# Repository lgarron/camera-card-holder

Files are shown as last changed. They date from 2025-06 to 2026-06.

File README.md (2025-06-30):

# Stacked camera card holder 

Presenting a compact "print-in-place" card holder to stack your SD cards or CFExpress B cards!

Video: https://www.youtube.com/watch?v=bbGzAtc4VuA

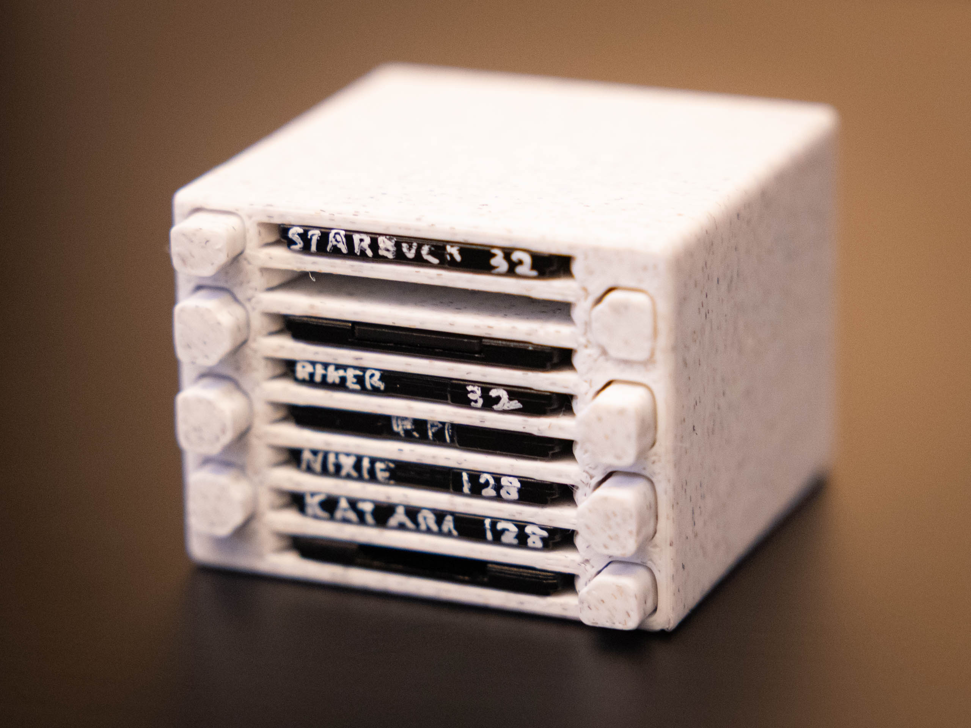
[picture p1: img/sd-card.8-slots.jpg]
Image of the 8-slot SD card variation


Find on MakerWorld at: https://makerworld.com/en/models/1563816-stacked-sd-card-cfexpress-type-b-card-holder

---------

I wanted something compact that I could attach to my desk, where all the cards can be individually accessed from the front with an "eject" button. I find the result to be very satisfying and practical.

Note that:

- The cards should stay in their slots during normal handling of the case, but this is *not* designed to take on-the-go. (But feel free to adapt the model to include a closing lid!)
- Versions are supported with 4/6/8/10 slots for both card types, and each build plate comes with a tool to snap the supports inside the model. (You only need this tool once per type of card, even if you print multiple designs with different numbers of slots.) Look at [1:25 in the video](https://www.youtube.com/watch?v=bbGzAtc4VuA&t=85s), or perform the following steps for each slot:
  - Hold the snapping tool with your index finger through the loop.
  - Insert into the slot so the longer side is up against the side that has the "eject" button for that slot.
  - Press down, keep the bottom of the tool on the eject button side, and move the top of the tool away.
  - If you really want to avoid using the the tool, you can place a card into a slot and then give it a strong and quick push. This should successfully snap the internal supports for materials in most prints, although I would still recommend using the snapping tool instead.
- The design is easily tuned for other card sizes (or even more slots), but I've only tested for SD cards and CFExpress Type B so far.
- I've found that the design looks and functions nicest using the following filaments
  - [PLA Marble — white](https://us.store.bambulab.com/products/pla-marble?id=41003162992776)
  - [PLA-CF — any color](https://us.store.bambulab.com/products/pla-cf)

The design is implemented entirely in OpenSCAD (https://openscad.org/) is open-sourced under the Creative Commands Attribution-ShareAlike 4.0 International license at: https://github.com/lgarron/camera-card-holder

## Building

This code uses:

- the snapshot channel of OpenSCAD, and
- the [`scad`](https://www.npmjs.com/package/scad) package on `npm`.

Here's an example of how to work on the code on macOS. I personally use [Homebrew](https://brew.sh/) to install `bun` and OpenSCAD:

```shell
brew install bun openscad@snapshot

git clone https://github.com/lgarron/camera-card-holder && cd camera-card-holder
make setup

open -a OpenSCAD ./*.scad
```

To build all variants the way I do, install `openscad-auto`:

```shell
brew install lgarron/lgarron/openscad-auto
make build-for-publish
make build
```

## Compatibility

Note that the code uses and unmerged and unreleased feature for OpenSCAD, naming its groups: https://github.com/openscad/openscad/pull/5942

Stable OpenSCAD is compatible with this, but may show warnings.

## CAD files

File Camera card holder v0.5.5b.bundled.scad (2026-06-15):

// Stacked camera card holder
// Lucas Garron
// v0.5.5 — manually bundled
// License: Creative Commons Attribution-NonCommercial-ShareAlike 4.0 International
//
// This file has been manually bundled and heavily modified to work around incompatibilities with Bambu's rendering vs. OpenSCAD.
// Therefore, it contains some extremely hacky and unmaintainable workarounds.
// For the original source, see: https://github.com/lgarron/camera-card-holder

CARD_TYPE = "SD Card"; // ["SD Card", "CFExpress B"]

NUMBER_OF_SLOTS = 4;

INCLUDE_CARD_TYPE_ENGRAVING = false;

/* [Debug] */

INCLUDE_DESIGN_VERSION_ENGRAVING = false;
DEBUG_EXCLUDE_CASING = false;

/* [Hidden] */

// This empty block prevents any following `CONSTANT_CASE` variables from being settable in the customizer.
// This prevents pathological interactions with persisted customizer values that are meant to be controlled exclusively by `VARIANT`.
{};

VARIANT = "default";

VERSION_TEXT = "v0.5.5b";

VARIANT_DATA = [
  [
    "default",
    [
      [
        ["DUAL_COLOR", false],
        ["DEEP_SECONDARY_COLOR", false],
        ["VARIANT_NUMBER_OF_SLOTS", NUMBER_OF_SLOTS],
        ["CF_EXPRESS_B", CARD_TYPE == "CFExpress B"],
        ["VARIANT_INCLUDE_DESIGN_VERSION_ENGRAVING", INCLUDE_DESIGN_VERSION_ENGRAVING],
      ],
    ],
  ],
  [
    "dual-color",
    [
      [
        ["DUAL_COLOR", true],
      ],
    ],
  ],
  [
    "deep-secondary-color",
    [
      [
        ["DEEP_SECONDARY_COLOR", true],
      ],
    ],
  ],
  [
    "6-slots",
    [
      [
        ["VARIANT_NUMBER_OF_SLOTS", 6],
      ],
    ],
  ],
  [
    "8-slots",
    [
      [
        ["VARIANT_NUMBER_OF_SLOTS", 8],
      ],
    ],
  ],
  [
    "10-slots",
    [
      [
        ["VARIANT_NUMBER_OF_SLOTS", 10],
      ],
    ],
  ],
  [
    "CFExpress-B",
    [
      [
        ["CF_EXPRESS_B", true],
      ],
    ],
  ],
  [
    "unengraved",
    [
      [
        ["VARIANT_INCLUDE_DESIGN_VERSION_ENGRAVING", false],
      ],
    ],
  ],
];
/*

// Allows specifying multiple variants to be rendered by `openscad-auto`: https://github.com/lgarron/dotfiles/blob/main/scripts/app-tools/openscad-auto.rs
//
// Each variant is a string, which must defined as an entry in a global BOSL2 struct named `VARIANT_DATA`.
//
// - The struct must contain an entry with the key `"default"`.
// - Keys are used in file names.
//   - They must not contain the character `.`, as this is used to compose variants (see below).
//   - Keys are used to create file names, so it is worth using names that will be as clear as possible in this context.
// - The value of each entry is a list containing:
//   - A required first item with a BOSL2 struct specifying a mapping of parameter names to values.
//   - An optional second item containing a list of parent variants to inherit from.
//     - Later entries override earlier entries.
//
// Each variant falls back to the parameter value from the `"default"` entry if it is not specified among the ancestors of a given entry.
// Note that the top-level order of entries has no effect on the parameter calculations. Parameter inheritance for a variant depends solely on the ordering of its parents (and their parents, recursively).
//
// The variant is specified in a global `VARIANT` var.
//
// - Multiple variants may be composed by specifying them with a `.` inbetween.
//   - Note that such variants can be defined explicitly in `VARIANT_DATA` by specifying those variants as parents. However, the compositional approach is a very convenient mechanism to avoid boilerplate.
//
// Parameters are computed by calling `get_parameter(parameter_name)` after `VARIANT` and `VARIANT_DATA` have been defined.
//
// Example usage:

VARIANT = "default"; // ["default", "no-version", "mini", "mini.normal-height"]

// This empty block prevents any following `CONSTANT_CASE` variables from being settable in the customizer.
// This prevents pathological interactions with persisted customizer values that are meant to be controlled exclusively by `VARIANT`.
{};

VARIANT_DATA = [
  [
    "default",
    [
      [
        ["TOTAL_HEIGHT", 5],
        ["TRIANGLE_EDGE_LENGTH", 25],
        ["INCLUDE_DESIGN_VERSION_ENGRAVING", true],
      ],
    ],
  ],
  [
    "no-version",
    [
      [
        ["INCLUDE_DESIGN_VERSION_ENGRAVING", false],
      ],
    ],
  ],
  [
    "mini",
    [
      [
        ["TOTAL_HEIGHT", 3],
        ["TRIANGLE_EDGE_LENGTH", 15],
      ],
      // Don't include the version for `mini` (it's small)
      ["no-version"]
    ],
  ],
  [
    "normal-height",
    [
      [
        ["TOTAL_HEIGHT", 5],
      ],
    ],
  ]
];

include <./node_modules/scad/variants.scad>

TOTAL_HEIGHT = get_parameter("TOTAL_HEIGHT");
TRIANGLE_EDGE_LENGTH = get_parameter("TRIANGLE_EDGE_LENGTH");
INCLUDE_DESIGN_VERSION_ENGRAVING = get_parameter("INCLUDE_DESIGN_VERSION_ENGRAVING");

*/

include <BOSL2/std.scad>

/*

type undef = undefined;
type ParameterValue = string | number;

type Struct<KeyType, ValueType> = [string, ValueType][];
type VariantID = string;
type ParameterName = string;
type VariantParameters = Struct<ParameterName, ParameterValue>;
type VariantInheritanceChain = VariantID[]; // Semantics: inheritance chain (later entries take priority)
type VariantEntry =
  | [VariantParameters]
  | [VariantParameters, VariantInheritanceChain];
type VariantData = Struct<VariantID, VariantEntry>;

// Global vars which must be set by the calling code.
export const VARIANT: string; // Variants delimited by `.`
export const VARIANT_DATA: VariantData;

*/

// function __variants__variant_parameters(variant_entry: VariantEntry): VariantParameters;
function __variants__variant_parameters(variant_entry) = variant_entry[0];
// function __variants__variant_parents(variant_entry: VariantEntry): [VariantID];
function __variants__variant_parents(variant_entry) = len(variant_entry) > 1 ? variant_entry[1] : [];

// function __variants__maybe_get_parameter_for_variant(parameter_name: ParameterName, variant_id: VariantID, variant_ids_in_recursion_stack_for_cycle_detection: VariantID[]): ParameterValue | undef;
function __variants__maybe_get_parameter_for_variant(parameter_name, variant_id, variant_ids_in_recursion_stack_for_cycle_detection) =
  // echo("__variants__maybe_get_parameter_for_variant", parameter_name, variant_id, variant_ids_in_recursion_stack_for_cycle_detection)
  assert(is_undef(str_find(variant_id, ".")), "Encountered a variant which contains the period (`.`) character. This character is used to delimit variants, and cannot be part of a variant ID directly")
  assert(!in_list(variant_id, variant_ids_in_recursion_stack_for_cycle_detection), str("Encountered recursively defined variants at the following variant: ", variant_id))
  let (
    variant_entry = struct_val(VARIANT_DATA, variant_id),
  ) assert(!is_undef(variant_entry), str("Variant is missing: ", variant_id)) // Technically we're doing unnecessary string concatentation in the "happy" path, but this should be cheap enough.
  let (
    direct_value = struct_val(__variants__variant_parameters(variant_entry), parameter_name)
  ) is_undef(direct_value) ? __variants__maybe_get_parameter_for_variants(parameter_name, __variants__variant_parents(variant_entry), concat(variant_ids_in_recursion_stack_for_cycle_detection, [variant_id])) : direct_value;;

// function __variants__maybe_get_parameter_for_variants(parameter_name: ParameterName, variants: VariantID[], variant_ids_in_recursion_stack_for_cycle_detection: VariantID[]): ParameterValue | undef;
function __variants__maybe_get_parameter_for_variants(parameter_name, variant_ids, variant_ids_in_recursion_stack_for_cycle_detection) =
  // echo("__variants__maybe_get_parameter_for_variants", parameter_name, variant_ids, variant_ids_in_recursion_stack_for_cycle_detection)
  len(variant_ids) == 0 ? undef
  : (
    let (maybe_value = __variants__maybe_get_parameter_for_variant(parameter_name, last(variant_ids), variant_ids_in_recursion_stack_for_cycle_detection)) is_undef(maybe_value) ? __variants__maybe_get_parameter_for_variants(parameter_name, list_head(variant_ids), variant_ids_in_recursion_stack_for_cycle_detection) : maybe_value
  );
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

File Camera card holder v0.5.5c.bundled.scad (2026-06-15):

// Stacked camera card holder
// Lucas Garron
// v0.5.5c — manually bundled
// License: Creative Commons Attribution-NonCommercial-ShareAlike 4.0 International
//
// This file has been manually bundled and heavily modified to work around incompatibilities with Bambu's rendering vs. OpenSCAD.
// Therefore, it contains some extremely hacky and unmaintainable workarounds.
// For the original source, see: https://github.com/lgarron/camera-card-holder

CARD_TYPE = "SD Card"; // ["SD Card", "CFExpress B"]

NUMBER_OF_SLOTS = 4;

INCLUDE_CARD_TYPE_ENGRAVING = false;

/* [Design parameters] */

CASING_OUTER_THICKNESS_X = 3.5;
CASING_OUTER_THICKNESS_Z = 2;
CASING_BACK_THICKNESS_Y = 1;
CASING_DISTANCE_BETWEEN_CARDS_Z = 1.5;

/* [Debug] */

INCLUDE_DESIGN_VERSION_ENGRAVING = false;
STRUCTURAL_COLORING = false;
DEBUG_EXCLUDE_CASING = false;

/* [Hidden] */

// Incompatible with Bambu rendering.
DUAL_COLOR = false;
DEEP_SECONDARY_COLOR = false;

// This empty block prevents any following `CONSTANT_CASE` variables from being settable in the customizer.
// This prevents pathological interactions with persisted customizer values that are meant to be controlled exclusively by `VARIANT`.
{};

module structural_color(color) {
  color(STRUCTURAL_COLORING ? color : "silver") {
    children();
  }
}

VARIANT = "default";

VERSION_TEXT = "v0.5.5c";

VARIANT_DATA = [
  [
    "default",
    [
      [
        ["VARIANT_DUAL_COLOR", DUAL_COLOR],
        ["VARIANT_DEEP_SECONDARY_COLOR", DEEP_SECONDARY_COLOR],
        ["VARIANT_NUMBER_OF_SLOTS", NUMBER_OF_SLOTS],
        ["CF_EXPRESS_B", CARD_TYPE == "CFExpress B"],
        ["VARIANT_INCLUDE_DESIGN_VERSION_ENGRAVING", INCLUDE_DESIGN_VERSION_ENGRAVING],
      ],
    ],
  ],
  [
    "dual-color",
    [
      [
        ["VARIANT_DUAL_COLOR", true],
      ],
    ],
  ],
  [
    "deep-secondary-color",
    [
      [
        ["VARIANT_DEEP_SECONDARY_COLOR", true],
      ],
    ],
  ],
  [
    "6-slots",
    [
      [
        ["VARIANT_NUMBER_OF_SLOTS", 6],
      ],
    ],
  ],
  [
    "8-slots",
    [
      [
        ["VARIANT_NUMBER_OF_SLOTS", 8],
      ],
    ],
  ],
  [
    "10-slots",
    [
      [
        ["VARIANT_NUMBER_OF_SLOTS", 10],
      ],
    ],
  ],
  [
    "CFExpress-B",
    [
      [
        ["CF_EXPRESS_B", true],
      ],
    ],
  ],
  [
    "unengraved",
    [
      [
        ["VARIANT_INCLUDE_DESIGN_VERSION_ENGRAVING", false],
      ],
    ],
  ],
];
/*

// Allows specifying multiple variants to be rendered by `openscad-auto`: https://github.com/lgarron/dotfiles/blob/main/scripts/app-tools/openscad-auto.rs
//
// Each variant is a string, which must defined as an entry in a global BOSL2 struct named `VARIANT_DATA`.
//
// - The struct must contain an entry with the key `"default"`.
// - Keys are used in file names.
//   - They must not contain the character `.`, as this is used to compose variants (see below).
//   - Keys are used to create file names, so it is worth using names that will be as clear as possible in this context.
// - The value of each entry is a list containing:
//   - A required first item with a BOSL2 struct specifying a mapping of parameter names to values.
//   - An optional second item containing a list of parent variants to inherit from.
//     - Later entries override earlier entries.
//
// Each variant falls back to the parameter value from the `"default"` entry if it is not specified among the ancestors of a given entry.
// Note that the top-level order of entries has no effect on the parameter calculations. Parameter inheritance for a variant depends solely on the ordering of its parents (and their parents, recursively).
//
// The variant is specified in a global `VARIANT` var.
//
// - Multiple variants may be composed by specifying them with a `.` inbetween.
//   - Note that such variants can be defined explicitly in `VARIANT_DATA` by specifying those variants as parents. However, the compositional approach is a very convenient mechanism to avoid boilerplate.
//
// Parameters are computed by calling `get_parameter(parameter_name)` after `VARIANT` and `VARIANT_DATA` have been defined.
//
// Example usage:

VARIANT = "default"; // ["default", "no-version", "mini", "mini.normal-height"]

// This empty block prevents any following `CONSTANT_CASE` variables from being settable in the customizer.
// This prevents pathological interactions with persisted customizer values that are meant to be controlled exclusively by `VARIANT`.
{};

VARIANT_DATA = [
  [
    "default",
    [
      [
        ["TOTAL_HEIGHT", 5],
        ["TRIANGLE_EDGE_LENGTH", 25],
        ["INCLUDE_DESIGN_VERSION_ENGRAVING", true],
      ],
    ],
  ],
  [
    "no-version",
    [
      [
        ["INCLUDE_DESIGN_VERSION_ENGRAVING", false],
      ],
    ],
  ],
  [
    "mini",
    [
      [
        ["TOTAL_HEIGHT", 3],
        ["TRIANGLE_EDGE_LENGTH", 15],
      ],
      // Don't include the version for `mini` (it's small)
      ["no-version"]
    ],
  ],
  [
    "normal-height",
    [
      [
        ["TOTAL_HEIGHT", 5],
      ],
    ],
  ]
];

include <./node_modules/scad/variants.scad>

TOTAL_HEIGHT = get_parameter("TOTAL_HEIGHT");
TRIANGLE_EDGE_LENGTH = get_parameter("TRIANGLE_EDGE_LENGTH");
INCLUDE_DESIGN_VERSION_ENGRAVING = get_parameter("INCLUDE_DESIGN_VERSION_ENGRAVING");

*/

include <BOSL2/std.scad>

/*

type undef = undefined;
type ParameterValue = string | number;

type Struct<KeyType, ValueType> = [string, ValueType][];
type VariantID = string;
type ParameterName = string;
type VariantParameters = Struct<ParameterName, ParameterValue>;
type VariantInheritanceChain = VariantID[]; // Semantics: inheritance chain (later entries take priority)
type VariantEntry =
  | [VariantParameters]
  | [VariantParameters, VariantInheritanceChain];
type VariantData = Struct<VariantID, VariantEntry>;

// Global vars which must be set by the calling code.
export const VARIANT: string; // Variants delimited by `.`
export const VARIANT_DATA: VariantData;

*/

// function __variants__variant_parameters(variant_entry: VariantEntry): VariantParameters;
function __variants__variant_parameters(variant_entry) = variant_entry[0];
// function __variants__variant_parents(variant_entry: VariantEntry): [VariantID];
function __variants__variant_parents(variant_entry) = len(variant_entry) > 1 ? variant_entry[1] : [];

// function __variants__maybe_get_parameter_for_variant(parameter_name: ParameterName, variant_id: VariantID, variant_ids_in_recursion_stack_for_cycle_detection: VariantID[]): ParameterValue | undef;
function __variants__maybe_get_parameter_for_variant(parameter_name, variant_id, variant_ids_in_recursion_stack_for_cycle_detection) =
  // echo("__variants__maybe_get_parameter_for_variant", parameter_name, variant_id, variant_ids_in_recursion_stack_for_cycle_detection)
  assert(is_undef(str_find(variant_id, ".")), "Encountered a variant which contains the period (`.`) character. This character is used to delimit variants, and cannot be part of a variant ID directly")
  assert(!in_list(variant_id, variant_ids_in_recursion_stack_for_cycle_detection), str("Encountered recursively defined variants at the following variant: ", variant_id))
  let (
    variant_entry = struct_val(VARIANT_DATA, variant_id),
  ) assert(!is_undef(variant_entry), str("Variant is missing: ", variant_id)) // Technically we're doing unnecessary string concatentation in the "happy" path, but this should be cheap enough.
  let (
    direct_value = struct_val(__variants__variant_parameters(variant_entry), parameter_name)
  ) is_undef(direct_value) ? __variants__maybe_get_parameter_for_variants(parameter_name, __variants__variant_parents(variant_entry), concat(variant_ids_in_recursion_stack_for_cycle_detection, [variant_id])) : direct_value;;

// function __variants__maybe_get_parameter_for_variants(parameter_name: ParameterName, variants: VariantID[], variant_ids_in_recursion_stack_for_cycle_detection: VariantID[]): ParameterValue | undef;
function __variants__maybe_get_parameter_for_variants(parameter_name, variant_ids, variant_ids_in_recursion_stack_for_cycle_detection) =
  // echo("__variants__maybe_get_parameter_for_variants", parameter_name, variant_ids, variant_ids_in_recursion_stack_for_cycle_detection)
  len(variant_ids) == 0 ? undef
  : (
    let (maybe_value = __variants__maybe_get_parameter_for_variant(parameter_name, last(variant_ids), variant_ids_in_recursion_stack_for_cycle_detection)) is_undef(maybe_value) ? __variants__maybe_get_parameter_for_variants(parameter_name, list_head(variant_ids), variant_ids_in_recursion_stack_for_cycle_detection) : maybe_value
  );
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

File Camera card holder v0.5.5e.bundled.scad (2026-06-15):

// Stacked camera card holder
// Lucas Garron
// v0.5.5c — manually bundled
// License: Creative Commons Attribution-NonCommercial-ShareAlike 4.0 International
//
// This file has been manually bundled and heavily modified to work around incompatibilities with Bambu's rendering vs. OpenSCAD.
// Therefore, it contains some extremely hacky and unmaintainable workarounds.
// For the original source, see: https://github.com/lgarron/camera-card-holder

CARD_TYPE = "SD Card"; // ["SD Card", "CFExpress B"]

NUMBER_OF_SLOTS = 4;

INCLUDE_CARD_TYPE_ENGRAVING = false;

/* [Design parameters] */

CASING_OUTER_THICKNESS_X = 3.5;
CASING_OUTER_THICKNESS_Z = 2;
CASING_BACK_THICKNESS_Y = 1;
CASING_DISTANCE_BETWEEN_CARDS_Z = 1.5;

/* [Debug] */

INCLUDE_DESIGN_VERSION_ENGRAVING = false;
STRUCTURAL_COLORING = false;
DEBUG_EXCLUDE_CASING = false;
DEBUG_SHOW_CROSS_SECTION = false;

/* [Hidden] */

// Incompatible with Bambu rendering.
DUAL_COLOR = false;
DEEP_SECONDARY_COLOR = false;

// This empty block prevents any following `CONSTANT_CASE` variables from being settable in the customizer.
// This prevents pathological interactions with persisted customizer values that are meant to be controlled exclusively by `VARIANT`.
{};

module structural_color(color_choice) {
  if (STRUCTURAL_COLORING) {
    color(color_choice) children();
  } else {
    children();
  }
}

VARIANT = "default";

VERSION_TEXT = "v0.5.5e";

VARIANT_DATA = [
  [
    "default",
    [
      [
        ["VARIANT_DUAL_COLOR", DUAL_COLOR],
        ["VARIANT_DEEP_SECONDARY_COLOR", DEEP_SECONDARY_COLOR],
        ["VARIANT_NUMBER_OF_SLOTS", NUMBER_OF_SLOTS],
        ["CF_EXPRESS_B", CARD_TYPE == "CFExpress B"],
        ["VARIANT_INCLUDE_DESIGN_VERSION_ENGRAVING", INCLUDE_DESIGN_VERSION_ENGRAVING],
      ],
    ],
  ],
  [
    "dual-color",
    [
      [
        ["VARIANT_DUAL_COLOR", true],
      ],
    ],
  ],
  [
    "deep-secondary-color",
    [
      [
        ["VARIANT_DEEP_SECONDARY_COLOR", true],
      ],
    ],
  ],
  [
    "6-slots",
    [
      [
        ["VARIANT_NUMBER_OF_SLOTS", 6],
      ],
    ],
  ],
  [
    "8-slots",
    [
      [
        ["VARIANT_NUMBER_OF_SLOTS", 8],
      ],
    ],
  ],
  [
    "10-slots",
    [
      [
        ["VARIANT_NUMBER_OF_SLOTS", 10],
      ],
    ],
  ],
  [
    "CFExpress-B",
    [
      [
        ["CF_EXPRESS_B", true],
      ],
    ],
  ],
  [
    "unengraved",
    [
      [
        ["VARIANT_INCLUDE_DESIGN_VERSION_ENGRAVING", false],
      ],
    ],
  ],
];
/*

// Allows specifying multiple variants to be rendered by `openscad-auto`: https://github.com/lgarron/dotfiles/blob/main/scripts/app-tools/openscad-auto.rs
//
// Each variant is a string, which must defined as an entry in a global BOSL2 struct named `VARIANT_DATA`.
//
// - The struct must contain an entry with the key `"default"`.
// - Keys are used in file names.
//   - They must not contain the character `.`, as this is used to compose variants (see below).
//   - Keys are used to create file names, so it is worth using names that will be as clear as possible in this context.
// - The value of each entry is a list containing:
//   - A required first item with a BOSL2 struct specifying a mapping of parameter names to values.
//   - An optional second item containing a list of parent variants to inherit from.
//     - Later entries override earlier entries.
//
// Each variant falls back to the parameter value from the `"default"` entry if it is not specified among the ancestors of a given entry.
// Note that the top-level order of entries has no effect on the parameter calculations. Parameter inheritance for a variant depends solely on the ordering of its parents (and their parents, recursively).
//
// The variant is specified in a global `VARIANT` var.
//
// - Multiple variants may be composed by specifying them with a `.` inbetween.
//   - Note that such variants can be defined explicitly in `VARIANT_DATA` by specifying those variants as parents. However, the compositional approach is a very convenient mechanism to avoid boilerplate.
//
// Parameters are computed by calling `get_parameter(parameter_name)` after `VARIANT` and `VARIANT_DATA` have been defined.
//
// Example usage:

VARIANT = "default"; // ["default", "no-version", "mini", "mini.normal-height"]

// This empty block prevents any following `CONSTANT_CASE` variables from being settable in the customizer.
// This prevents pathological interactions with persisted customizer values that are meant to be controlled exclusively by `VARIANT`.
{};

VARIANT_DATA = [
  [
    "default",
    [
      [
        ["TOTAL_HEIGHT", 5],
        ["TRIANGLE_EDGE_LENGTH", 25],
        ["INCLUDE_DESIGN_VERSION_ENGRAVING", true],
      ],
    ],
  ],
  [
    "no-version",
    [
      [
        ["INCLUDE_DESIGN_VERSION_ENGRAVING", false],
      ],
    ],
  ],
  [
    "mini",
    [
      [
        ["TOTAL_HEIGHT", 3],
        ["TRIANGLE_EDGE_LENGTH", 15],
      ],
      // Don't include the version for `mini` (it's small)
      ["no-version"]
    ],
  ],
  [
    "normal-height",
    [
      [
        ["TOTAL_HEIGHT", 5],
      ],
    ],
  ]
];

include <./node_modules/scad/variants.scad>

TOTAL_HEIGHT = get_parameter("TOTAL_HEIGHT");
TRIANGLE_EDGE_LENGTH = get_parameter("TRIANGLE_EDGE_LENGTH");
INCLUDE_DESIGN_VERSION_ENGRAVING = get_parameter("INCLUDE_DESIGN_VERSION_ENGRAVING");

*/

include <BOSL2/std.scad>

/*

type undef = undefined;
type ParameterValue = string | number;

type Struct<KeyType, ValueType> = [string, ValueType][];
type VariantID = string;
type ParameterName = string;
type VariantParameters = Struct<ParameterName, ParameterValue>;
type VariantInheritanceChain = VariantID[]; // Semantics: inheritance chain (later entries take priority)
type VariantEntry =
  | [VariantParameters]
  | [VariantParameters, VariantInheritanceChain];
type VariantData = Struct<VariantID, VariantEntry>;

// Global vars which must be set by the calling code.
export const VARIANT: string; // Variants delimited by `.`
export const VARIANT_DATA: VariantData;

*/

// function __variants__variant_parameters(variant_entry: VariantEntry): VariantParameters;
function __variants__variant_parameters(variant_entry) = variant_entry[0];
// function __variants__variant_parents(variant_entry: VariantEntry): [VariantID];
function __variants__variant_parents(variant_entry) = len(variant_entry) > 1 ? variant_entry[1] : [];
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

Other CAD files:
Camera card holder v0.5.5f.bundled.scad
Camera card holder v0.4.0.scad
Camera card holder v0.4.1.scad
Camera card holder v0.4.10.scad
Camera card holder v0.4.12.scad
Camera card holder v0.4.13.scad
Camera card holder v0.4.14.scad
Camera card holder v0.4.15.scad
Camera card holder v0.4.16.scad
Camera card holder v0.4.17.scad
Camera card holder v0.4.18.scad
Camera card holder v0.4.19.scad
Camera card holder v0.4.2.scad
Camera card holder v0.4.20.scad
Camera card holder v0.4.21.scad
Camera card holder v0.4.23.scad
Camera card holder v0.4.24.scad
Camera card holder v0.4.3.scad
Camera card holder v0.4.4.scad
Camera card holder v0.4.5.scad
Camera card holder v0.4.6.scad
Camera card holder v0.4.7.scad
Camera card holder v0.4.8.scad
Camera card holder v0.4.9.scad
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

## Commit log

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2024-12-21 Increase the wall thickness between the card and the ejector plunger.
    [Camera card holder v0.4.1.scad]
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2024-12-21 Add snappable axle supports for printing.
    [Camera card holder v0.4.1.scad]
2024-12-21 v0.4.1
    Release notes:
    - Increase the wall thickness between the card and the ejector plunger, for more subtle leverage and a larger available
    front surface that can be turned into a button.
    - Increase ejector plunger depth to compensate.
    - Add a bigger ejector button.
    - Add snappable axle supports for printing.
    [Camera card holder v0.4.1.scad.3mf]
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2024-12-21 Swap to a single axle print support.
    [Camera card holder v0.4.2.scad]
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2024-12-21 Adjust how close ejector plunger and lever distance are at printing time.
    [Camera card holder v0.4.2.scad]
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2024-12-21 Increase lever clearances from the casing a bit.
    [Camera card holder v0.4.2.scad]
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2024-12-21 v0.4.2
    - Swap to a single axle print support.
    - Reduce `EJECTOR_PLUNGER_WALL_CLEARANCE` to 0.3.
    - Adjust how close ejector plunger and lever distance are at printing time.
    - Thicken the lever around the axle.
    - Add lever printing supports.
    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
    [Camera card holder v0.4.2.scad.3mf]
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2024-12-21 Remove one of the axle snap connectors.
    [Camera card holder v0.4.3.scad]
2024-12-21 Change the lever to be thicker throughout more of its length.
    [Camera card holder v0.4.3.scad]
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2024-12-21 v0.4.3
    - Remove one of the axle snap connectors.
    - Change the lever to be thicker throughout more of its length.
    - Reduce `EJECTOR_PLUNGER_WALL_CLEARANCE` further to 0.25.
    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
    [Camera card holder v0.4.3.scad.3mf]
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2024-12-21 Fix the plunger front button width.
    [Camera card holder v0.4.4.scad]
2024-12-21 v0.4.4
    - Fix the plunger front button width.
    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
    [Camera card holder v0.4.4.scad.3mf]
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2024-12-21 Use two half-sized springs on each side instead of a single one.
    [Camera card holder v0.4.5.scad]
2024-12-21 Carve space for the card tab to enable the card to sit flush in front.
    [Camera card holder v0.4.5.scad]
2024-12-21 v0.4.5
    - Use two half-sized springs on each side instead of a single one.
    - Carve space for the card tab to enable the card to sit flush in front.
    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
    [Camera card holder v0.4.5.scad.3mf]
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2024-12-21 Remove an extra char in the change notes.
    [Camera card holder v0.4.6.scad]
2024-12-21 v0.4.6
    - Change the spring compression to be lighter.
    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
    [Camera card holder v0.4.6.scad.3mf]
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2024-12-21 Change the spring compression to be even lighter.
    [Camera card holder v0.4.7.scad]
2024-12-21 v0.4.7
    - Change the spring compression to be even lighter.
    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
    [Camera card holder v0.4.7.scad.3mf]
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2024-12-21 Change the axle holder to only have extra print clearance on the supported side.
    [Camera card holder v0.4.8.scad]
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2024-12-21 v0.4.8
    - Change the axle holder to only have extra print clearance on the supported side.
    - Inset the axle for a flush casing.
    - Lengthen the lever to require less leverage.
    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
    [Camera card holder v0.4.8.scad.3mf]
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2024-12-21 Adjust the axle inset further to accommodate double-wall slicing.
    [Camera card holder v0.4.9.scad]
2024-12-21 v0.4.9
    - Adjust the axle inset further to accommodate double-wall slicing.
    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
    [Camera card holder v0.4.9.scad.3mf]
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2024-12-21 Change the spring compression to be even lighter (again).
    [Camera card holder v0.4.10.scad]
2024-12-21 v0.4.10
    - Decrease text engraving depth.
    - Change the spring compression to be even lighter (again).
    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
    [Camera card holder v0.4.10.scad.3mf]
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2024-12-21 Decrease the depth of the casing (and adjust the lever to compensate).
    [Camera card holder v0.4.10.scad]
2024-12-21 v0.4.11
    - Decrease `EJECTOR_PLUNGER_WALL_CLEARANCE`.
    - Decrease the depth of the casing (and adjust the lever to compensate).
    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
    [Camera card holder v0.4.10.scad.3mf]
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2024-12-21 Implement stacking and set the design to 4 slots.
    [Camera card holder v0.4.12.scad]
2024-12-21 v0.4.12
    - Implement stacking.
    - Set the design to 4 slots.
    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
    [Camera card holder v0.4.12.scad.3mf]
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2024-12-22 Ensure the axle holes and plunger chutes are properly carved from adjacent stacked casings.
    [Camera card holder v0.4.13.scad]
2024-12-22 v0.4.13
    - Ensure the axle holes and plunger chutes are properly carved from adjacent stacked casings.
    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
    [Camera card holder v0.4.13.scad.3mf]
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2024-12-22 v0.4.14
    - Increase `EJECTOR_PLUNGER_WALL_CLEARANCE` to 0.2.
    - Set the number of slots to 2 for testing.
    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
    [Camera card holder v0.4.14.scad.3mf]
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2024-12-22 Fix the axle hole and plunger chute carving forrealz.
    [Camera card holder v0.4.15.scad]
2024-12-22 Decrease the plunger wall clearance for the head.
    [Camera card holder v0.4.15.scad]
2024-12-22 Decrease the back spring compression to an even further negative value.
    [Camera card holder v0.4.15.scad]
2024-12-22 Increase the number of slots to 3 for testing.
    [Camera card holder v0.4.15.scad]
2024-12-22 v0.4.15
    - Fix the axle hole and plunger chute carving forrealz.
    - Decrease the plunger wall clearance for the head.
    - Decrease the back spring compression to an even further negative value.
    - Increase the number of slots to 3 for testing.
    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
    [Camera card holder v0.4.15.scad.3mf]
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2024-12-22 v0.4.16
    - Reduce back spring compression even more.
    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
    [Camera card holder v0.4.16.scad.3mf]
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2024-12-22 Round the entire array instead of individual slot blocks.
    [Camera card holder v0.4.17.scad]
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2024-12-22 v0.4.17
    - Round the entire array instead of individual slot blocks.
    - Increase the number of slots to 4.
    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
    [Camera card holder v0.4.17.scad.3mf]
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2024-12-22 `compose()` all blocks instead of duplicating code for carveouts.
    [Camera card holder v0.4.18.scad]
2024-12-22 v0.4.18
    - `compose()` all blocks instead of duplicating code for carveouts.
    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
    [Camera card holder v0.4.18.scad.3mf]
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2024-12-22 Adjust the lever calculations so they also work for SD card sizes.
    [Camera card holder v0.4.19.scad]
2024-12-22 v0.4.19
    - Adjust the lever calculations so they also work for SD card sizes.
    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
    [Camera card holder v0.4.19.scad.3mf]
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2024-12-24 Avoid cutting the plunger when extended.
    [Camera card holder v0.4.20.scad]
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2024-12-24 Increase the vertical height of the plunger front.
    [Camera card holder v0.4.20.scad]
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2024-12-24 v0.4.20
    - Use parametric calculations for the plunger.
    - Avoid cutting the plunger when extended.
    - Increase the vertical height of the plunger front.
    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
    [Camera card holder v0.4.20.scad.3mf]
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2024-12-24 Adjust plunger dimensions to accommodate the SD card size.
    [Camera card holder v0.4.21.scad]
2024-12-24 Include 4 output objects: 1 CFexpress, 1 SD card, 4 CFexpress, 4 SD card
    [Camera card holder v0.4.21.scad]
2024-12-24 v0.4.21
    - Adjust plunger dimensions to accommodate the SD card size.
    - Include 4 output objects: 1 CFexpress, 1 SD card, 4 CFexpress, 4 SD card
    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
    [Camera card holder v0.4.21.scad.3mf]
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2024-12-24 Remove the card tab negative from SD cards.
    [Camera card holder v0.4.22.scad]
2024-12-24 Add extra height in the middle (on both sides) for sticker labels.
    [Camera card holder v0.4.22.scad]
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2024-12-31 Add a torque smoothing curve to the lever for easier smooth ejection (without shooting out the card).
    [Camera card holder v0.4.23.scad]
2024-12-31 v0.4.23
    - Add a torque smoothing curve to the lever for easier smooth ejection (without shooting out the card).
    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
    [Camera card holder v0.4.23.scad.3mf]
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2025-06-22 Add `tsconfig.json` to get VS Code to stop marking top-level `await` as errors.
    [Camera card holder v0.5.1.scad]
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2025-06-22 Increase casing outer thickness for (hopefully) more reliable printability and stability.
    [Camera card holder v0.5.1.scad]
2025-06-23 v0.5.1
    - Add `CFExpress-B.8-slots.dual-color.deep-secondary-color` variant.
    - Increase casing outer thickness for (hopefully) more reliable printability and stability.
    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
2026-06-15 `bun add --dev -- '@cubing/dev-config@>=0.10.1' && bun x --package bun-dedupe@0.0.5 dedupe -- && bun install` (roll)
    Deduplicating deps like this is the current best workaround for: https://github.com/oven-sh/bun/issues/1343
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2026-06-15 Fix up prepublish checks.
    [Camera card holder v0.5.5i.bundled.scad]
2026-06-15 Bump (and pin) GH actions to avoid warnings.
